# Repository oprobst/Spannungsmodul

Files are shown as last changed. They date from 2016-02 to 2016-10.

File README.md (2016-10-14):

# Spannungsversorgungsmodul

Microcontroller based toggle to supply other modules with power.

  * The start time can be configured by a timer. 
  * Low voltage monitoring
  * Provide 5V stabilized and supply voltage to 3rd party modules
  * Timer and voltage visualization by LED

## Usage

When connected to power, the module will start to delivery a stabilized 5V and the supply voltage to a 3rd party component after a configured amount of time.

### Start timer configuration

The module start in status OFF. When initializing it send an switch-off signal to the relay to ensure status.

When the module is connected to power, it waits a few seconds for user input (defined by constant SEC_TILL_ON, default is 10 sec). Every button operation in OFF mode will increase this wait time. When the button is pushed less than 1 sec, the wait time will be increased by StartupTimer#SMALL_TIMER_VALUE (default = 10min). When pushed longer than a second, it will be increased by StartupTimer#BIG_TIMER_VALUE (default = 60min). This time is calculated based on the initial start-up of the module (first connectivity with supply voltage).
The current wait time is visualized by the status LED: Long blink interval means a big waiting duration, short blink interval means that the system waits a complete small timer duration until it starts. A very short flash signals end of wait time visualization. This will apply every 15 seconds when waiting in OFF mode.

When the wait time is exposed, the system will signal two times short-long blinking. Then it activates the mosfet transistors.
It changes to status ON.

### Voltage monitoring
Within this status, the system visualizes every 15 seconds the current voltage measurement. According to the Jumper JP4, it measures the distance from full battery to 9V or 6V (2 or 3 cell LiPo Battery) cut-off voltage. The maximum voltage is not defined by software, a zener diode will restrict it and protect the ADC. Actually, the maximum voltage is defined by hardware and is somewhere around 30V (depending on DCDC converter).

The voltage will be visualized by the flashing LED. The more often the LED flashes, the longer is the distance from current voltage to cut-off voltage. 

When voltage reaches the cut-off voltage (defined by main#ADC_TRESHOLD, default = 660), the LED will fast flash for a around 3 seconds and then initialize the shutdown procedure. Next, the module will visualize the shut-down by two seconds of long-sort LED blinking. Afterwards the relay, as well as the mosfet, will be triggered off. On low voltage shutdown, the microcontroller will be send to power saving sleep mode (SLEEP_MODE_PWR_DOWN). This can only be reverted, when turning supply voltage off and on again (reset).

When the button is pushed during ON mode, she shutdown procedure will also activated. In opposite to the voltage cut-off, this will not trigger a power saving sleep mode. But all timers (including startup-time) will be reset and the system is in OFF mode. Then everything starts again.

## Set-up

Once started, it activates the transistors toggling input voltage to the target system. Maximum current is 5 ampere (depending on mosfet).

In addition, it provides a PIN output for a 5V DCDC converted voltage. Maximum current is restricted to 1 ampere (depending on DCDC Converter).

To protect the battery, a low voltage detection for 3s (12.6V to 9.2V) and 2s (8.4V to 6V) LiPo batteries is available. This is configured by the jumper.

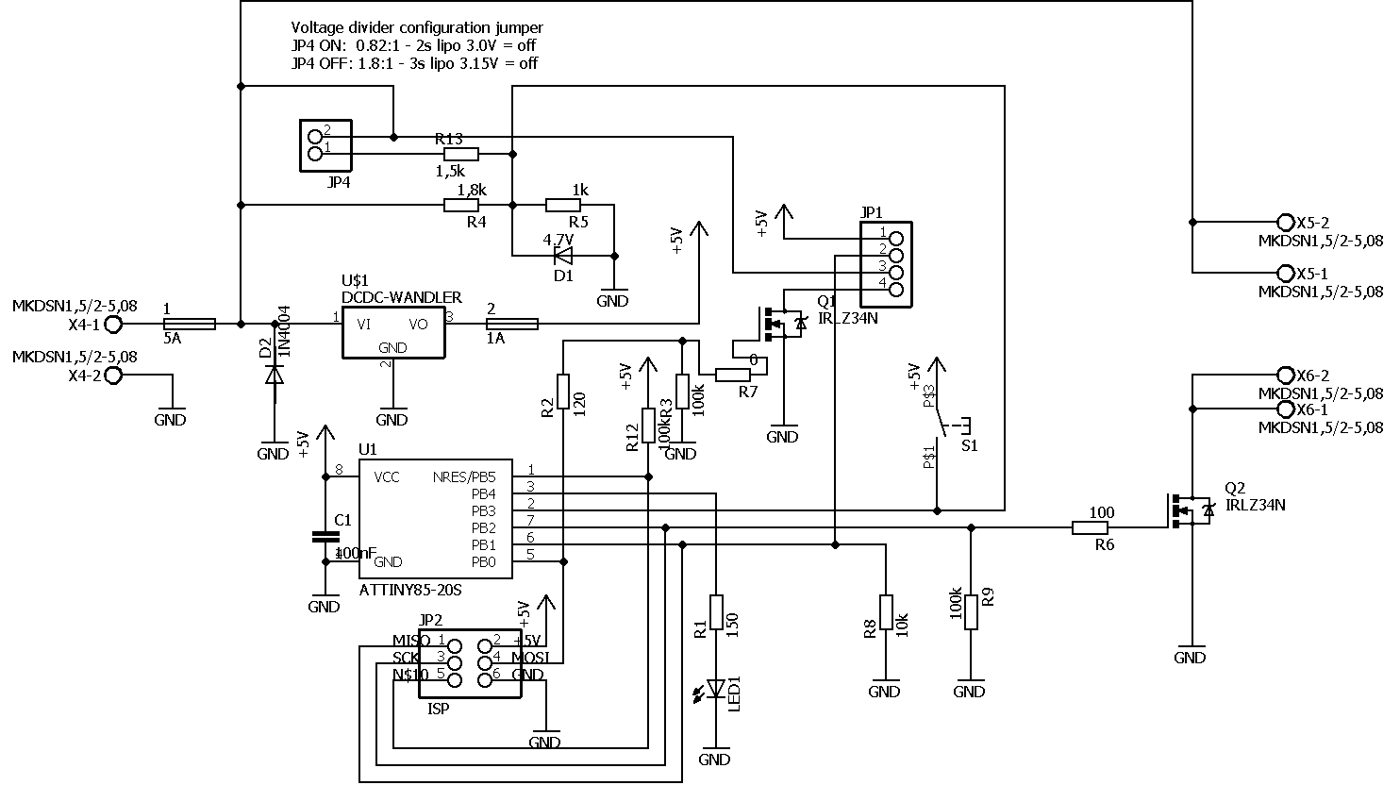
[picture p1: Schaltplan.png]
Exported schematic for the module Schematic

(_For newest schematic, please check the original eagle files!_)

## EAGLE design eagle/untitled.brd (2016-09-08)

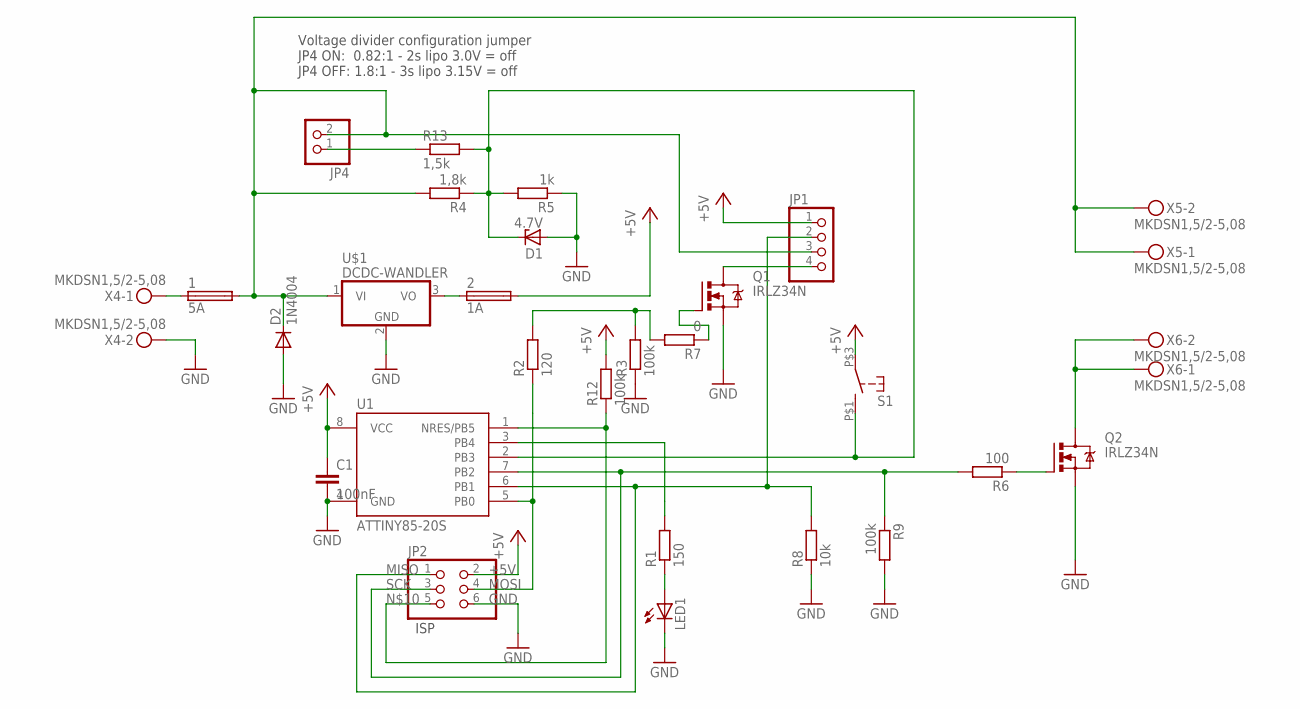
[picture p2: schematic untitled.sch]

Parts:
1: 5A; SH22,5A
2: 1A; SH22,5A
C1: 100nF; C0805
D1: 4.7V; SOT23
D2: 1N4004; DO41-10
JP1: PINHD-1X4; 1X04
JP2: PINHD-2X3; 2X03
JP4: PINHD-1X2; 1X02
LED1: LED3MM
Q1, Q2: IRLZ34N; TO220BH
R1: 150; R1206
R2: 120; R1206
R3, R9, R12: 100k; R1206
R4: 1,8k; R1206
R5: 1k; R1206
R6: 100; R1206
R7: 0; R1206
R8: 10k; R1206
R13: 1,5k; R1206
S1: SCHLIESSER_TASTSCHALTER; NAMAE-JTP-1130
U1: ATTINY85-20S; SOIC8_EIAJ_208MIL
U$1: DCDC-WANDLER; TRACOPOWER-DCDCWANDER-TSR1
X4, X5, X6: MKDSN1,5/2-5,08

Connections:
+5V: 2.2, C1.1, JP1.1, JP2.2, R12.2, S1.P$3 (4), U1.8 (VCC)
GND: C1.2, D1.1 (A), D2.A, JP2.6, LED1.K (C), Q1.S, Q2.S, R3.1, R5.1, R8.1, R9.2, U1.4 (GND), U$1.2 (GND), X4.2
MISO: JP1.2, JP2.1, R8.2, U1.6 (PB1)
MOSI: JP2.4, R2.1, U1.5 (PB0)
unnamed: 1.1, X4.1
unnamed: 1.2, D2.C, JP1.3, JP4.2, R4.2, U$1.1 (VI), X5.1, X5.2
unnamed: Q2.D, X6.1, X6.2
unnamed: Q2.G, R6.1
unnamed: LED1.A, R1.1
unnamed: Q1.G, R7.1
unnamed: R2.2, R3.2, R7.2
unnamed: JP2.5, R12.1, U1.1 (NRES/PB5)
unnamed: R1.2, U1.3 (PB4)
unnamed: JP4.1, R13.1
unnamed: 2.1, U$1.3 (VO)
unnamed: JP1.4, Q1.D
RESET: D1.3 (C), R4.1, R5.2, R13.2, S1.P$1 (3), U1.2 (PB3)
SCK: JP2.3, R6.2, R9.1, U1.7 (PB2)

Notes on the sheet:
Voltage divider configuration jumper JP4 ON: 0.82:1 - 2s lipo 3.0V = off JP4 OFF: 1.8:1 - 3s lipo 3.15V = off
ISP

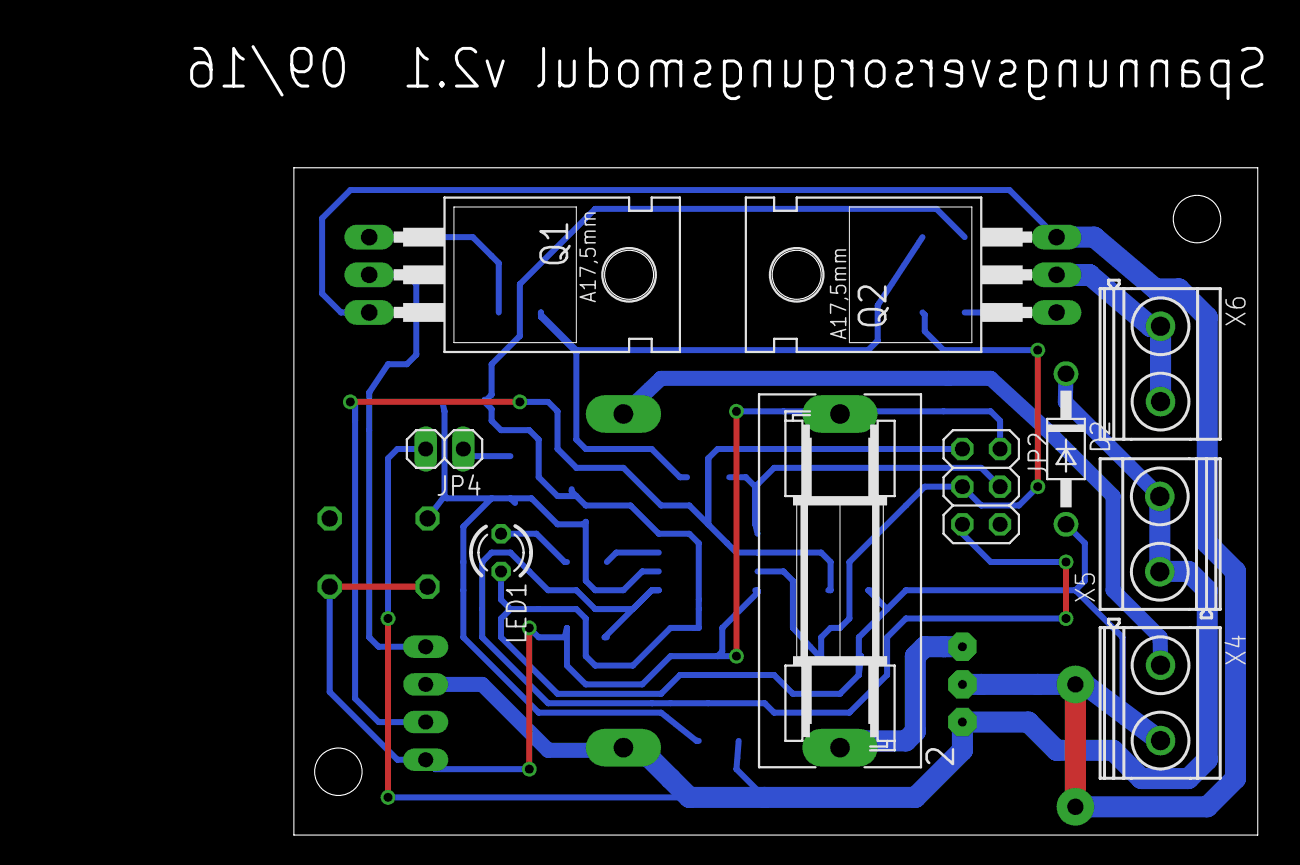
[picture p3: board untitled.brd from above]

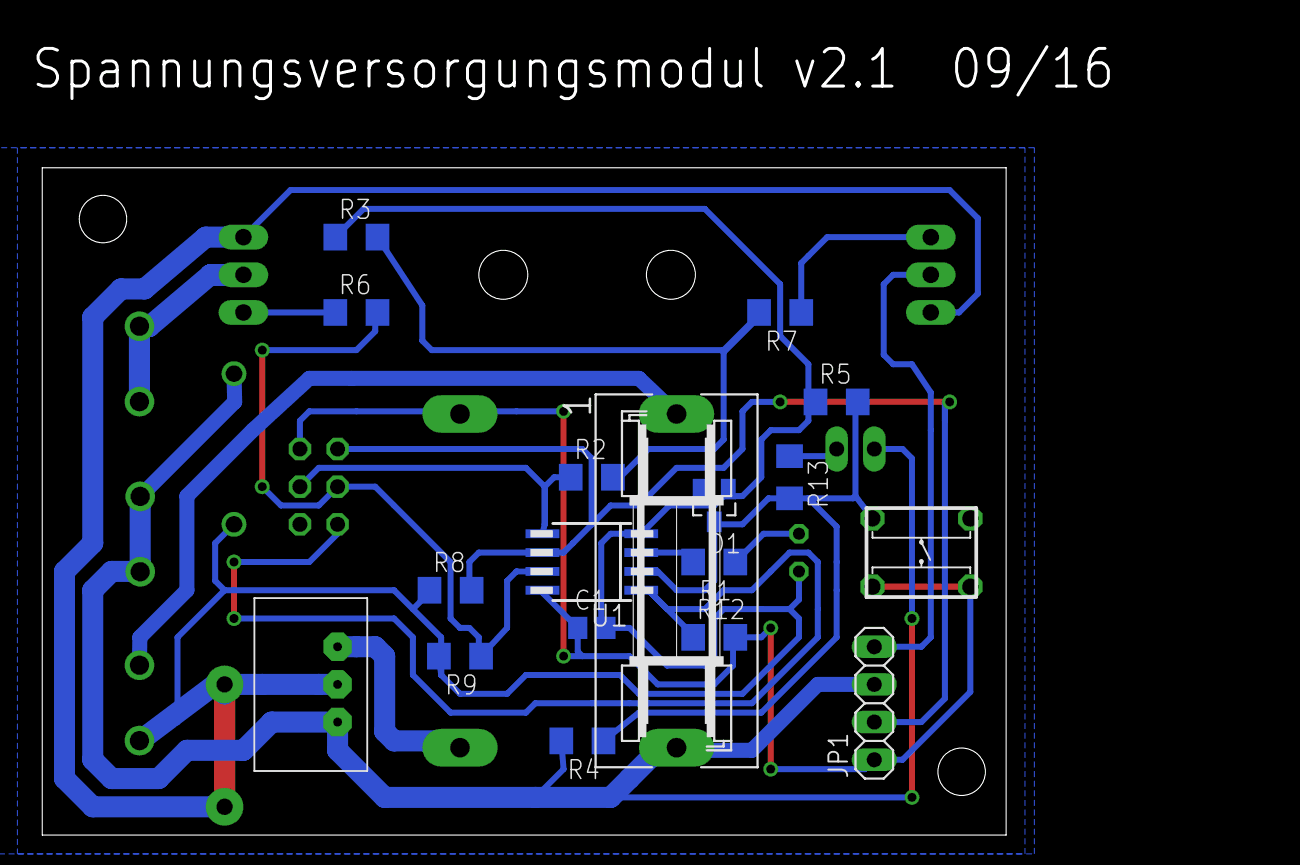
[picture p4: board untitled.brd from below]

Board: 2 copper layers, 65.0 x 45.0 mm, 28 parts (18 on the bottom side), 18 nets.

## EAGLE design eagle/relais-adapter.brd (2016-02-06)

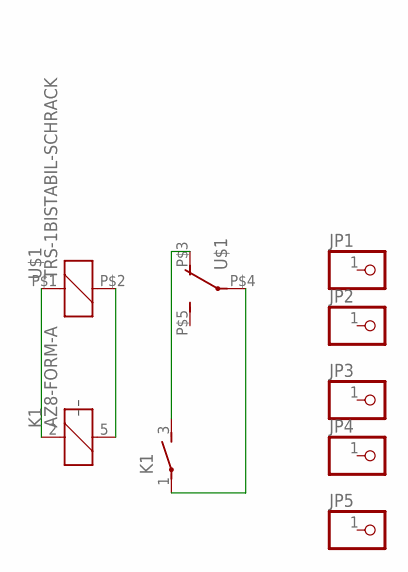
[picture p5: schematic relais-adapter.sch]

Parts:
JP1, JP2, JP3, JP4, JP5: PINHD-1X1; 1X01
K1: AZ8-FORM-A; AZ8
U$1: TRS-1BISTABIL-SCHRACK; PRINTRELAIS-SCHRACK-PE-BISTABIL

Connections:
unnamed: K1.2 (1), U$1.P$1 (1)
unnamed: K1.5 (2), U$1.P$2 (2)
unnamed: K1.3 (S), U$1.P$3 (O)
unnamed: K1.1, U$1.P$4

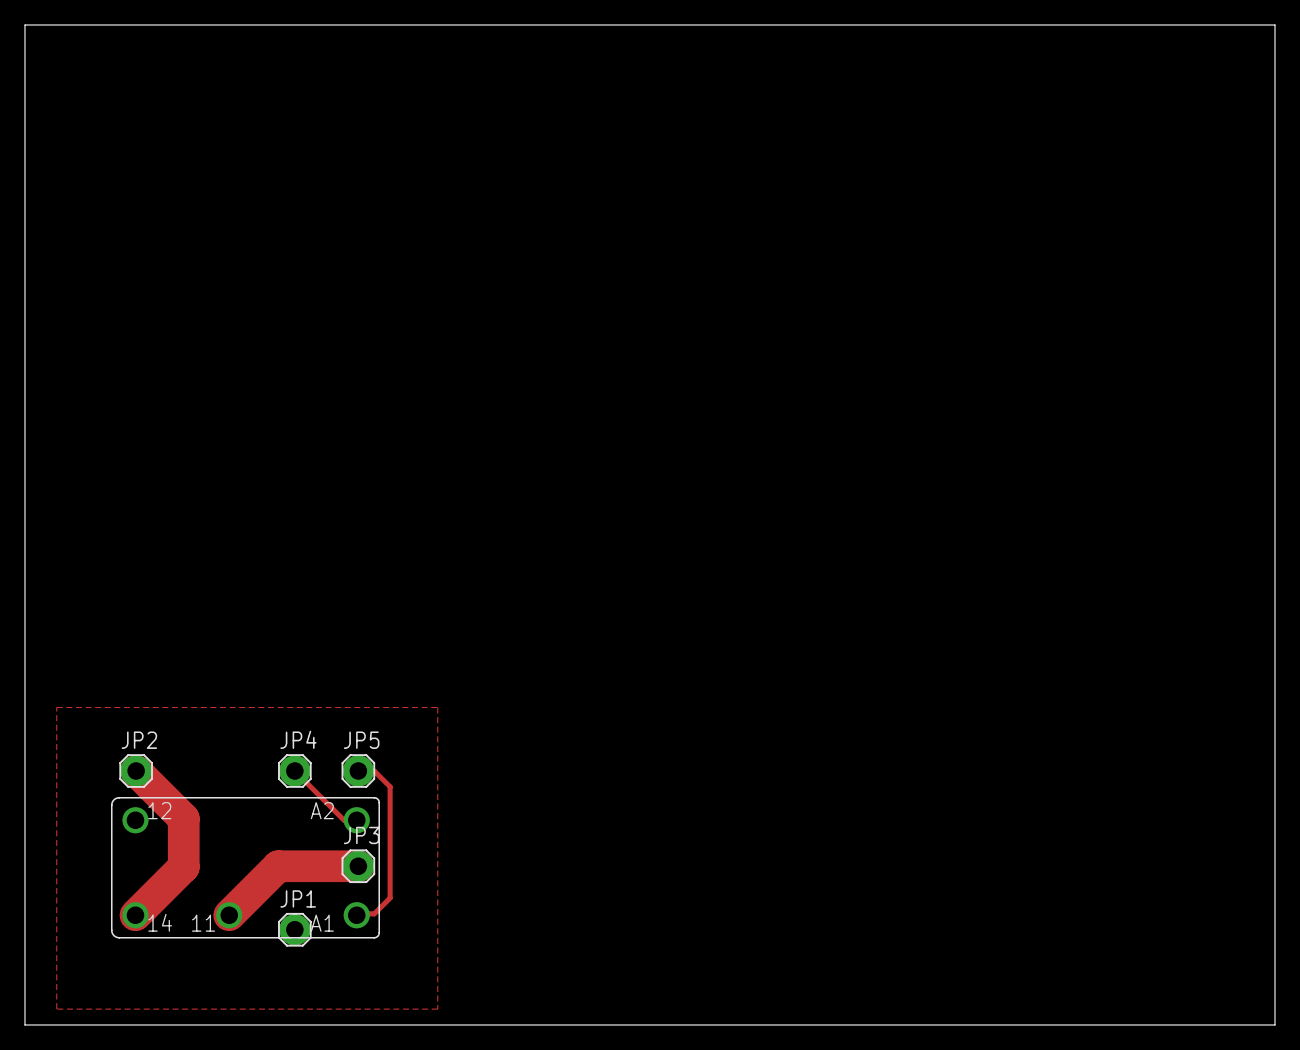
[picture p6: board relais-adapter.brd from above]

Board: 2 copper layers, 100.0 x 80.0 mm, 7 parts (1 on the bottom side), 4 nets.

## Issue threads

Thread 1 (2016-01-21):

Enhancements

oprobst, 2016-01-21:
Pullup Resistor at Reset

Closed 2016-01-27.

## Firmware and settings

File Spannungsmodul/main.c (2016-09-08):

#include <avr/io.h>
#include <avr/sleep.h>
#include <util/delay.h>
#include <stdint.h>
#include <avr/interrupt.h>
#include <avr/wdt.h>

#include "VoltageCheck.h"
#include "StartupTimer.h"
#include "PowerSwitch.h"
#include "Stopwatch.h"

#define F_CPU 1000000UL //1 MHz

#define SEC_TILL_ON 10

#define ADC_TRESHOLD 660

#define TRUE 1
#define FALSE 0

/*
 * Main method, will initialize Ports and handle timers, shutdown voltage
 * and button input by user.
 */
int main(void)
{
	
	//out:
	//PB1,PB2 -> Relais
	//PB4 LED
	//PB0 MOSFET
	//in:
	//PB3 ADC for voltage measurement
	DDRB |= ((0 << PB1) |(1 << PB2) |(0 << PB3) |(1 << PB4) | (1 << PB0));
	
	initADC(ADC_TRESHOLD);
	PORTB &= ~(1 << PB2);
	PORTB &= ~(1 << PB0);
	
	PORTB |= (1<<PB4);
	_delay_ms(200);
	PORTB &= ~(1<<PB4);
	_delay_ms(200);
	PORTB |= (1<<PB4);
	_delay_ms(200);
	PORTB &= ~(1<<PB4);
	
	start();
	sei();
	startStopwatch();

	while( 1 ) {
		
		checkForShutdown ();
		
		checkForButton();
		
		if (getSecondsSinceStart() > SEC_TILL_ON){
			if (isOn() == FALSE ){
				checkIfTimeIsOver();
				if ((getSecondsSinceStart() % 15) == 0){
					visualizeTimer(PB4);
				}
			} else {
				sleep ();
			}
		}
		
	}
}

/*
 * Busy waiting. Check button input from time to time.
 * (could be reimplemented by interrupts somewhere in the future...)
 */
void sleep (){
	int8_t i;
	for (i = 0; i < 100; i++){
		checkForButton();
		_delay_ms(100); // 10 sec
		// an interrupt would be more useful here... But anyway, it works.
	}
	visualizeVoltage(PB4);
}

/*
* Check if voltage divider is bridged by switch.
* If longer than 1 sec. pushed, call longButtonPush method, shortButtonPush otherwise.
*/
void checkForButton (void){
	if (readADCsamples(1) > 1000){
		uint8_t i;
		for ( i = 0; i < 10; i++){
			_delay_ms(100);
			if (readADCsamples(3) <= 1000){
				shortButtonPush();
				return;
			}
		}
		longButtonPush();
	}
}

/*
 * Will be called on long button push. Triggers increase of big timer duration.
 * Should also do a reset when system is ON, but this doesn't working...?
 */
void longButtonPush (){
	
	if (isOn()){
		//reset
		wdt_enable(WDTO_15MS);
		for(;;) {}
		} else {
		addBigTimer ();
		visualizeTimer(PB4);
		startStopwatch();
	}
}

/*
 * Short button push was detected. 
 */
void shortButtonPush (){
	
	if (isOn()){
		//shutdown
		startStopwatch();
		resetTimer();
		switchOff();
		
		} else {
		
		addSmallTimer ();
		visualizeTimer(PB4);
		startStopwatch();
	}
}

/*
 * Check if shutdown voltage has been reached.
 * Power down everything in this case.
 */
void checkForShutdown (void){
	
	if (shutdownVoltageReached()){
		cli(); //disable interrupts
		for (uint8_t i = 0; i< 100; i++){
			_delay_ms(35);
			PINB |= (1<<PB4); //Invert PB4
		}		
		switchOff();
		// Go to sleep and only wake up on reset/power switch.		
		PORTB &= ~(1<<PB4); // LED off
		set_sleep_mode(SLEEP_MODE_PWR_DOWN);
		sleep_enable();
		sleep_cpu();
		sleep_disable();
		//here everything should be silent. If we reach the next while loop, something is wrong.
		while (1){
			_delay_ms(1500);
			PINB |= (1<<PB4); //Invert PB4
		}
	}
}
	

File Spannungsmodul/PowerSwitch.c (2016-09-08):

#include <stdint.h>
#include <avr/io.h>
#include <util/delay.h>
#define TRUE 1
#define FALSE 0

uint8_t isStarted = FALSE;
#define TIME_TO_SIGNAL_START 2 // x2 sec
#define TIME_TO_SIGNAL_STOP 2 // x2 sec
#define RELAY_SWITCH_TIME 250 //ms
#define RELAY_SWITCH_RETRY 1 //times



void switchOn (void){
	// blink 2 seconds
	for (uint8_t i = 0; i< TIME_TO_SIGNAL_START ; i++ ){
		PORTB |= (1<<PB4); //Invert PB4
		_delay_ms(300);
		PORTB &= ~(1 << PB4);
		_delay_ms(300);
		PORTB |= (1<<PB4); 
		_delay_ms(800);
		PORTB &= ~(1 << PB4);
		_delay_ms(600);
	}
	isStarted = TRUE;
	PORTB |= (1<<PB0);
	PORTB |= (1<<PB2);
	
}

void switchOff (void){
	// blink delay
	isStarted = FALSE;	
	for (uint8_t i = 0; i < TIME_TO_SIGNAL_STOP; i++ ){
			PORTB |= (1<<PB4); 
			_delay_ms(800);
			PORTB &= ~(1 << PB4);
			_delay_ms(300);
			PORTB |= (1<<PB4);
			_delay_ms(300);
			PORTB &= ~(1 << PB4);
			_delay_ms(600);
	}
	
	 
	PORTB &= ~(1<<PB0);
	PORTB &= ~(1<<PB2);
	
}

uint8_t isOn (void){
	return isStarted;
}

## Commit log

2016-01-21 Initial check in
    [untitled.brd, untitled.sch]
2016-01-21 Added resistor for npn transistors
    [untitled.brd, untitled.sch]
2016-01-21 Pullup- reset & 2x voltage divider
    [untitled.brd, untitled.sch]
2016-01-26 Additional jumper for 2s and 3s lipo battery
    [untitled.brd, untitled.sch]
2016-01-26 First experiments with ADC
2016-01-27 A lot of new code for timer, switch and voltage check
2016-01-27 Changed relais. Fixed compiler failures
    [untitled.brd, untitled.sch]
2016-01-28 =setup of timer implemented
2016-01-29 Updated info text in diagram
    [untitled.sch]
2016-01-29 Update README.md
    Translated to english and added schematics and explanation of jumpers
2016-01-29 Added list format for connector description
2016-02-06 Adapter from wrong package in V1.1 to V1.2
    [relais-adapter.brd, relais-adapter.sch]
2016-02-08 Lots of essential changes to functionality
    [untitled.brd, untitled.sch]
2016-02-09 Close to done. Added correct timer and voltage visualization and calculation
    [VoltageCheck.c, main.c]
2016-02-09 bugfix low voltage detection
    [PowerSwitch.c, VoltageCheck.c, main.c]
2016-02-10 Added hint about eagle files to the schematic
2016-02-10 Minor bugfixes for timer. Added reset function for restart.
    [PowerSwitch.c, main.c]
2016-09-08 Updated to version 2.1 with mosfets instead of a relay
    [untitled.brd, untitled.sch]
2016-10-14 Updated readme to new version without relay
